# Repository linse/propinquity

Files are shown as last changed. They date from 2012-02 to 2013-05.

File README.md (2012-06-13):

Propinquity
===========

Propinquity is a full-body game that is a hybrid between fighting and dancing games. Two players wear proximity sensors on different body parts and as they move to the music, different sensors patches on their bodies light up to indicate when they are active. The players attempt to get as close as possible to active patches on the other player’s body to score points. The longer s(he) can stay “in the sweet spot” (but without actually touching), the higher the resulting score.

[Propinquity on the TAG website](http://playpr.hexagram.ca/projects/?proj=2)

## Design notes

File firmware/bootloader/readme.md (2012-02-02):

Propinquity Arduino Bootloader
==============================

In order to flash the Arduino bootloader onto the propinquity patch, simply run "make". You must make sure the port/programmer in the makefile match the port and programmer you are using.

It is important to use this makefile and NOT the bootloader flashing available in the Arduino IDE. The flashing in the Arduino IDE has the wrong clock rate and it will brick your propinquity patch.

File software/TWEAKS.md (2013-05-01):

# Where To Tweak Things in Propinquity

* Enable the hardware simulation IMPORANT MUST BE SET TO FALSE TO PLAY WITH REAL PATCHES
	* Location src/Propinquity.java line 28
	* Name: useSimulator
	* Range: true/false
	* Set to true if you need to use the hardware simulator, set to false if you're using real patches
* Adjust the prox sensor ranges
	* Location: src/hardware/Patch.java line 14-5
	* Name: MIN_RANGE, MAX_RANGE
	* Range: 0-1024 (actual maximum is closer to 1000, depends on prox sensors)
	* Adjust the range of the prox sensor in which you can score. MIN_RANGE, MAX_RANGE sets the range in which normal scoring occurs. Outside this range no scoring occurs
* Player Colors
	* Location src/PlayerConstants.java line 22-27
	* Name: PLAYER_COLORS, NEUTRAL_COLOR
	* Range: see the src/Color.java file for more colors
	* This sets the colors everywhere for neutral and players.
hes/gloves
* ProxLevel (normal levels) length
	* Location: src/ProxLevel.java line 17
	* Name: TOTAL_LEN
	* Range: > 0 (number in milliseconds)
	* Sets the total length of a ProxLevel in millisecond. For example set 180000ms for 180sec/3min
* Background Color Saturation
	* Location: src/LevelConstants.java line 17
	* Name: BACKGROUND_SAT_CAP
	* Range: 0-1
	* This number limits the maximum color saturation of the background when one player is winning. 0 being no saturation and 1 being full saturation
* Blinking speeds and duty cycle
	* Location: src/hardware/HardwareConstants.java line 15-18
	* Name: SLOW_BLINK, FAST_BLINK
	* Range: > 0 (in milliseconds)
	* Name: DEFAULT_DUTY_CYCLE
	* Range: 0-255 (0 -> 0%, 127 -> 50%, 255 -> 100%)
	* Sets the fast and slow blink speeds for the patches/gloves. You can also set how much of each blink period is on/off by adjusting the DEFAULT_DUTY_CYCLE
* Particle Sizes
	* Location: src/Particle.java line 17-20
	* Name: SMALL_SIZE, LARGE_SIZE, METABALL_OVERSIZE_FACTOR
	* Range: > 0
	* Set the size of the small and large particles. The METABALL_OVERSIZE_FACTOR affects how aggressively the particles "melt" into each other
* Particle spawning rates
	* Location: src/Player.java line 13-16
	* Name: SPAWN_DELAY_SHORT
	* Name: SPAWN_DELAY_MED
	* Name: SPAWN_DELAY_LONG (Not used right now, only used with SweetSpot)
	* Name: SPAWN_DELAY_TAU
	* Range: > 0
	* Sets the spawning rate of particles according to an exponential curve. SPAWN_DELAY_MED is the initial rate of spawning (in milliseconds). SPAWN_DELAY_SHORT is the final rate of spawning (in milliseconds). SPAWN_DELAY_TAU adjust the time the exponential curve takes to go from slow to fast (in milliseconds). The equations are on line 275 and 278.
* Patch and glove XBee addresses
	* Location src/PlayerConstants.java line 12-20
	* Name: PATCH_ADDR, GLOVE_ADDR
	* Range: > 0
	* Gives the Xbees addresses for the patches and gloves

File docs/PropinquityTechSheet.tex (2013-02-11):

\documentclass{article}

\pagestyle{empty} %Clear header and footer

\usepackage{times} %Font
\usepackage{soul} %Spacing

\usepackage{graphicx} %Images
\usepackage{subfig} %Subfigures

\usepackage{hyperref} %Link everything

\usepackage{enumitem}

\usepackage[small,compact]{titlesec} %Save on space between titles/sections

\graphicspath{{./media/}} %image folder

\begin{document}

\title{Propinquity - Technical Sheet \\ \vspace{-2em}}
\date{\today}

\maketitle

% \clearpage

\section*{Patch and Glove Features}

Each patch/glove is completely independent and uniquely addressed. Sensor values and feedback can be configured on a per patch/glove basis.

\subsection*{Communication}

\begin{itemize}[noitemsep,nolistsep]
	\item Xbees: bi-directional serial communication with computer.
	\item Serial port: programing port (arduino compatible) and serial communication.
\end{itemize}

\subsection*{Sensors}

\begin{itemize}[noitemsep,nolistsep]
	\item Proximity Sensor -- Sharp GP2D120 sensor: \\ Senses proximity in a 4 to 30 cm ranges. The sensor is connected to the patch/glove by a cable and could be mounted away from the main patch/glove. \\ {\em Propinquity gloves currently do not include proximity sensors.}
	\item Accelerometer -- MMA8452Q 3-axis accelerometer. \\ In addition to 3-axis acceleration information, the sensor has a number of built in event detection mechanisms detailed below.
\end{itemize}

\subsection*{Feedback}

\begin{itemize}[noitemsep,nolistsep]
	\item RGB LEDs. \\ 4 high brightness RGB LEDs (controlled together) are located in the corners of the patch/glove.
	\item Vibe Motor. \\ The coin cell vibe motor is connected via a cable and mounted separately. \\ {\em Proinquity patches do not currently include vibe motors.}
\end{itemize}

\subsection*{Expansion Ports}

The propinquity patches/gloves include 4 expansion ports connected to ADC pins (can also be used as digital pins). These are equivalent to the arduino A0, A1, A2 and A3 pins.

\pagebreak

\section*{Accelerometer Details}

\subsection*{General Functionality}

\begin{itemize}[noitemsep,nolistsep]
	\item 3-axis accelerometer sensor
	\item Adjustable sensitivity range (+- 2/4/8 G)
\end{itemize}

\subsection*{Special Functionality}

The accelerometer has specical functionality built in to detect certain events. These functions provide very robust and easy detection method. Technical details are available in the data-sheet.

\begin{itemize}[noitemsep,nolistsep]
	\item {\bf Freefall Detection:} \\ Detect the acceleration magnitude falling below a threshold. Often used to detect if the accelerometer is dropped and falling freely. Additionally a minimum time before triggering can be set (debouncing), this forces the condition to occur continuously for a certain interval of time before the event is confirmed.
	\item {\bf Motion Detection:} \\ Detect when the acceleration magnitude rises above a set threshold. Often used to detect the device being in use. Additionally a minimum time before triggering can be set (debouncing), this forces the condition to occur continuously for a certain interval of time before the event is confirmed.
	\item {\bf Transient Detection:} \\ Similar to motion detection but optionally pre-filtered with a high pass filter. This will remove constant acceleration such as gravity.
	\item {\bf Pulse Detection:} \\ Allows detection of pulses or taps, single or double. \\ ``Embedded single/double and directional pulse detection. This function has various customizing timers for setting the pulse time width and the latency time between pulses. There are programmable thresholds for all three axes. The pulse detection can be configured to run through the high-pass filter and also through a low-pass filter, which provides more customizing and tunable pulse-detection schemes.''
	\item {\bf Orientation Detection:} \\ ``Orientation detection algorithm with the ability to detect all 6 orientations.''
\end{itemize}

\end{document}

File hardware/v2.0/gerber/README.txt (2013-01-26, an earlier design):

Contact
------------------
Designer:

Specifications
------------------
* Green solder mask
* White silkscreen (top layer only)
* 3mils tolerance on drills
* 7mils spacings everywhere (checked)

Files
------------------
*.drd : 	excellon drill data
*.cmp : 	copper layer (TOP)
*.sol : 	copper layer (BOTTOM)
*.stc : 	soldermask layer (TOP)
*.sts : 	soldermask layer (BOTTOM)
*.plc : 	silkscreen layer (TOP)
*.pls : 	silkscreen layer (BOTTOM)

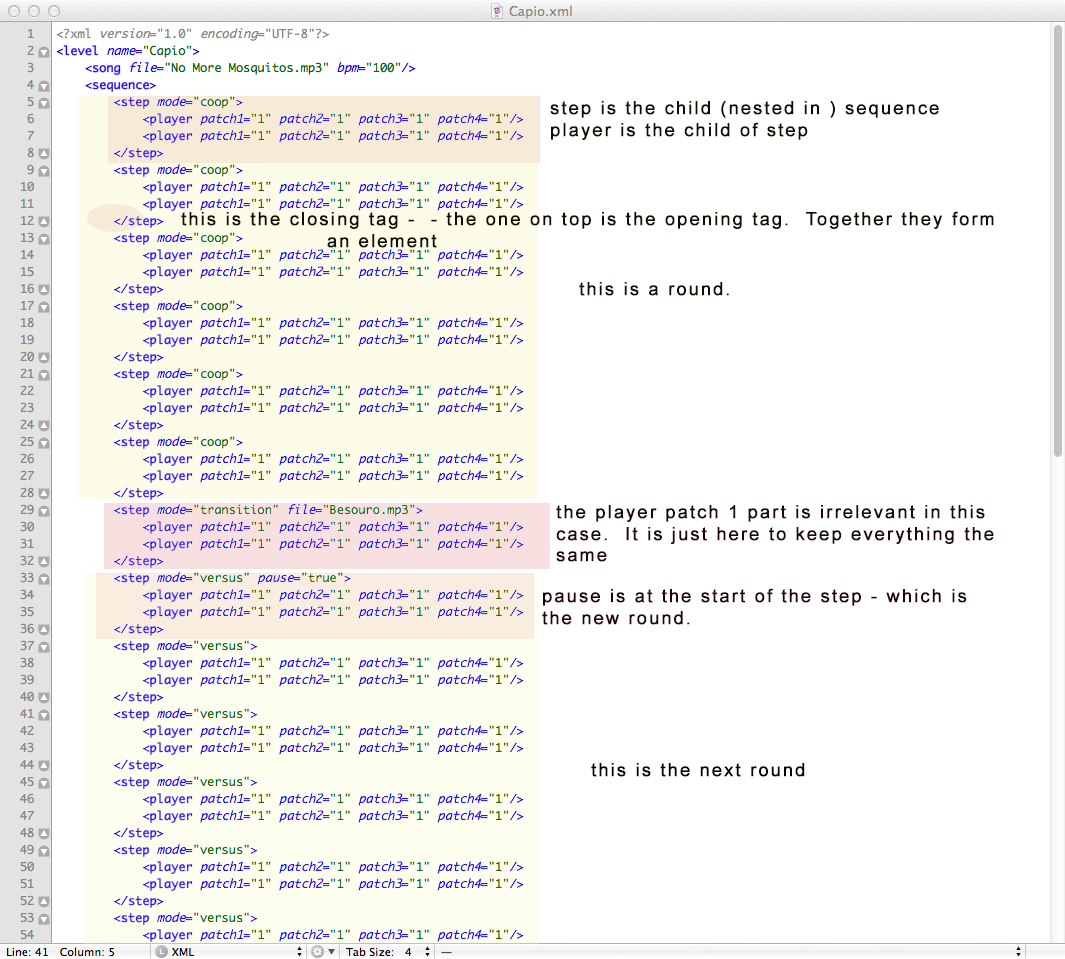
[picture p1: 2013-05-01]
docs/level.png

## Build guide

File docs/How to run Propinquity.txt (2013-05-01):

https://github.com/linse/propinquity

click on zip Ð and this is the latest.

Unzip

Open terminal

CD (change directory) command to go into the directory

CD Òname of directoryÓ  (or I can grab the folder I just unzipped and drag it next to CD space Ðpropinquity>software)
For example:
Janes-Mac-Pro:~ janetingley$ cd /Users/janetingley/Desktop/propinquity/Source\ Code/propinquity-May1/software

(I can also write ls (list) if I want to see what is in the directory.)

then type Ð ant

should run Ð if not Ð check the error message.  (if not Ð perhaps missing sound files?)

There is a launcher Ð Propinquity> software > launchers    may or may not work

Vocab

Level is comprised of 4 rounds

Details

Space bar Ð to move through the program when it is running.
Delete Ð backwards
Esc Ð quit
E Ð end Ð jumps to end
s- skip current level and goes to next transition
a Ð adjust the visuals (circle) and arrow keys Ð x and y axis.

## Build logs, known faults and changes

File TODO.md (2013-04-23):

# Propinquity TODOs

## Documentation
* High level documentation
	* OO diagram
	* Protocol specifications

## XBees
* XBee configuration should be saved and added to the git repo
* A new correct record of the XBee addresses should be added to the repo
* We need two full radio address spaces and a mechanism to switch between them.

## Work Schedule

My high level plan for the first block of time (24h) looks like this.

 * Review the new hardware. (8-12h)
 	* Make any improvements I can to the current boards (such as changing regulator etc).
 * Review software from the hackathon (4-8h)
 	* Read new code (particularly from marius)
 	* Organize and document a bit so it's a least somewhat maintainable
 * Examine and address what bugs I can such as those in my notes and from Marius' notes (8h+)
 * If time remains start think about the accelerometers

The other block of time (20h) was mainly for working with the accel. I'm thinking something like this.

 * Provide some examples of advanced accelerometer use for future reference
 * Consider some amendments to the Xbee protocol to work better with accel
 * Prototype the often discussed speed limited version of the basic propinquity game
 * Play test this prototype in the TAG lab

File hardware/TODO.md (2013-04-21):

# Hardware TODOs

## V2.0 Hardware

### Known Issues

* Regulator footprint accepts active low EN 3.3V regulators. This seems to be less common than active high especially with for LDOs with >100mA or more of current. This is a problem since is seems that we require at least that much current.
* No pins available for connecting a switch
* Topology of the circuit is not good for charging since everything is connected and running when you try and charge. This means the charger can't tell what's going on
* FTDI +5V connects directly to the +3v3 net, probably not nice for the +3v3 chips (e.g. accel and prox)
* Transistor is uncommon footprint (EBC?)
* The setup is unnecessarily connected to +3v3. It would draw less current and be more power efficient in general to run it off V+

### Current Status and Workarounds

* For regulator Some 100mA regulators are available with the current pinout, but current drive is marginal
* Alternatively use any pin with active high EN, bend up the pin and use a small wire to connect EN to closest V+
* Switches have been added by bending up the V+ pin on the battery Molex connector and putting a switch between the +ve leg of the molex connector and the V+ pad.
* Charging doesn't seem like it's consistently working. Probably have to disconnect batteries for the moment
* Ignoring FTDI issue for now. Pin could be removed from the header if it's an issue
* More common BCE or equivalent MOSFET can be installed upside down easily

## V2.1 Hardware

### Fixes

* Regulator footprint has active high EN polarity. Can accept bigger +3.3V regulators
* Added header for a switch that leave only the charger plugged in when it's in the off position. This should allow on/off and good charging
* +5V from the FTDI connector now connects to V+ via a jumper. This is optional for dev. In general it's probably not good to have the +5V attached to V+ since you risk damaging the battery.
* Flipped transistor footprint
* Step up runs directly off V+
* New routing of the PCB is 10mil tolerant where possible

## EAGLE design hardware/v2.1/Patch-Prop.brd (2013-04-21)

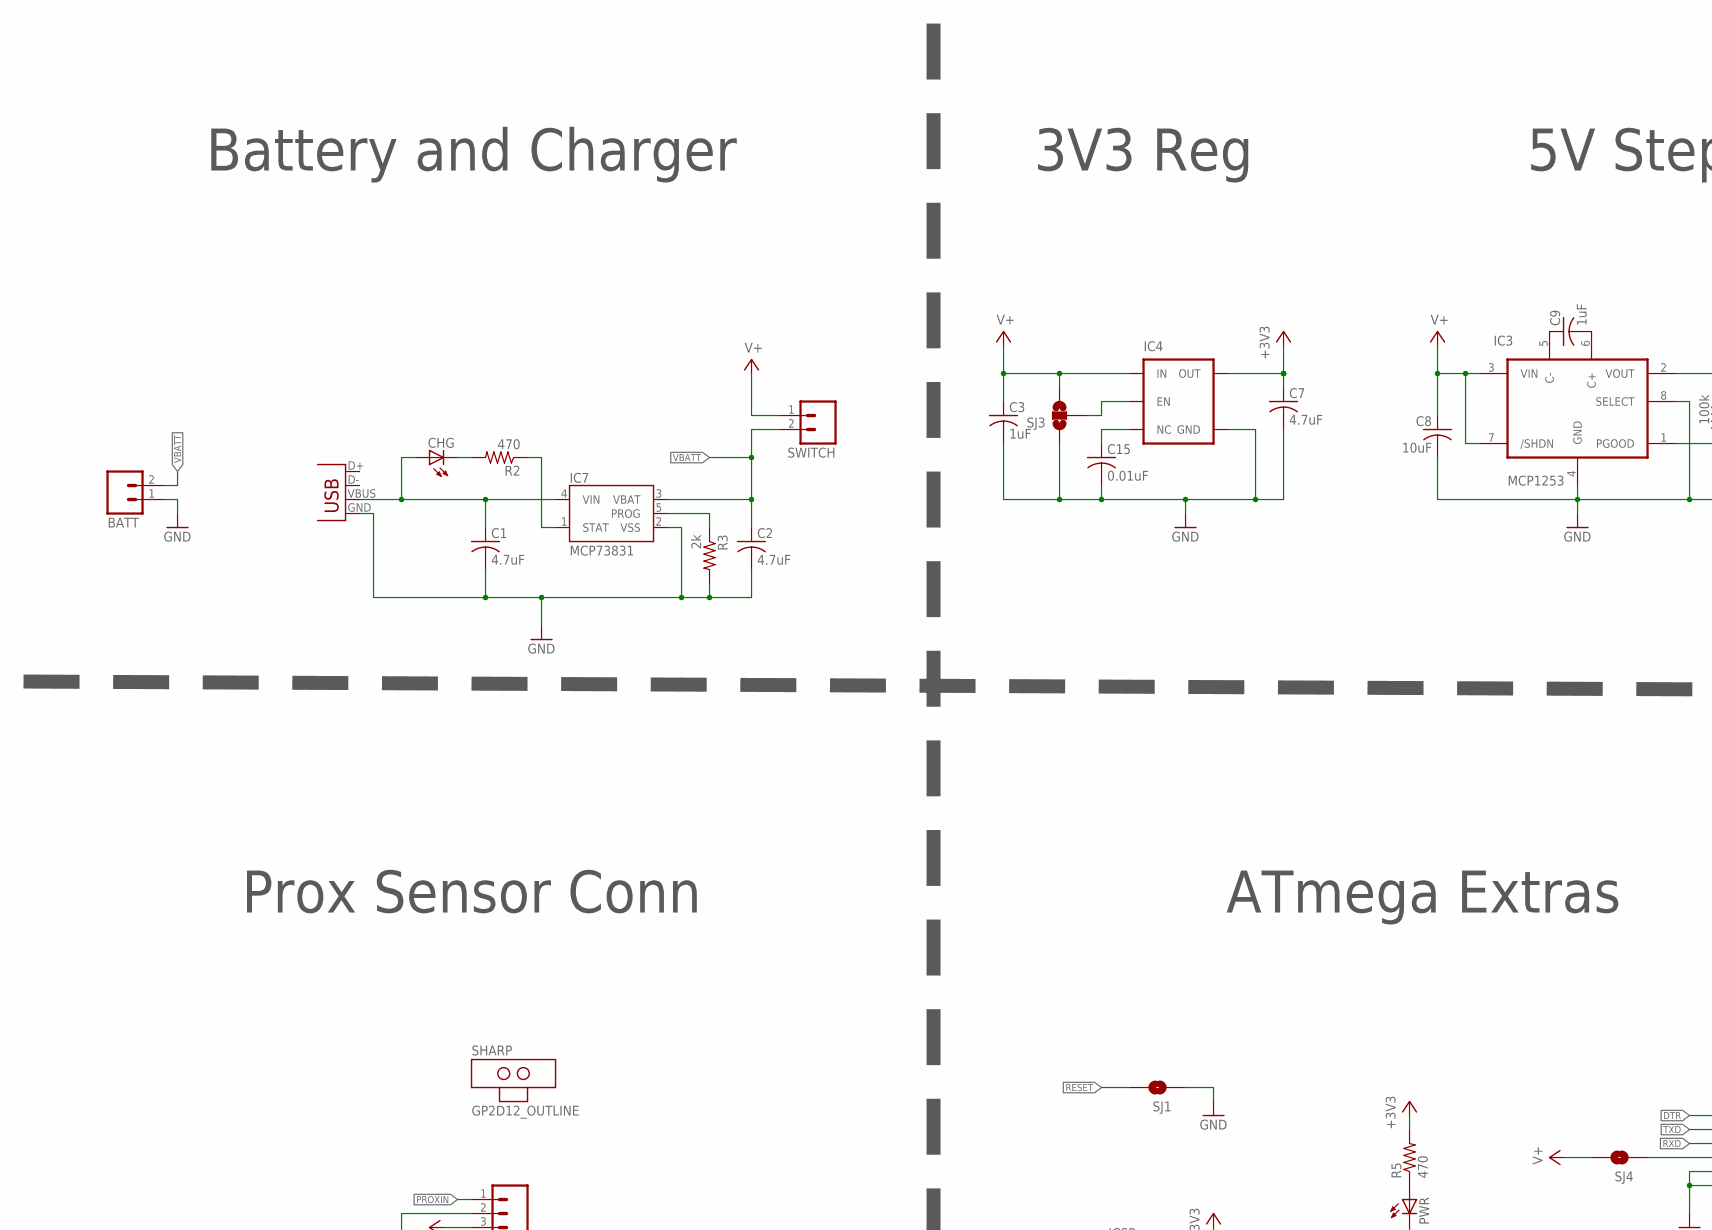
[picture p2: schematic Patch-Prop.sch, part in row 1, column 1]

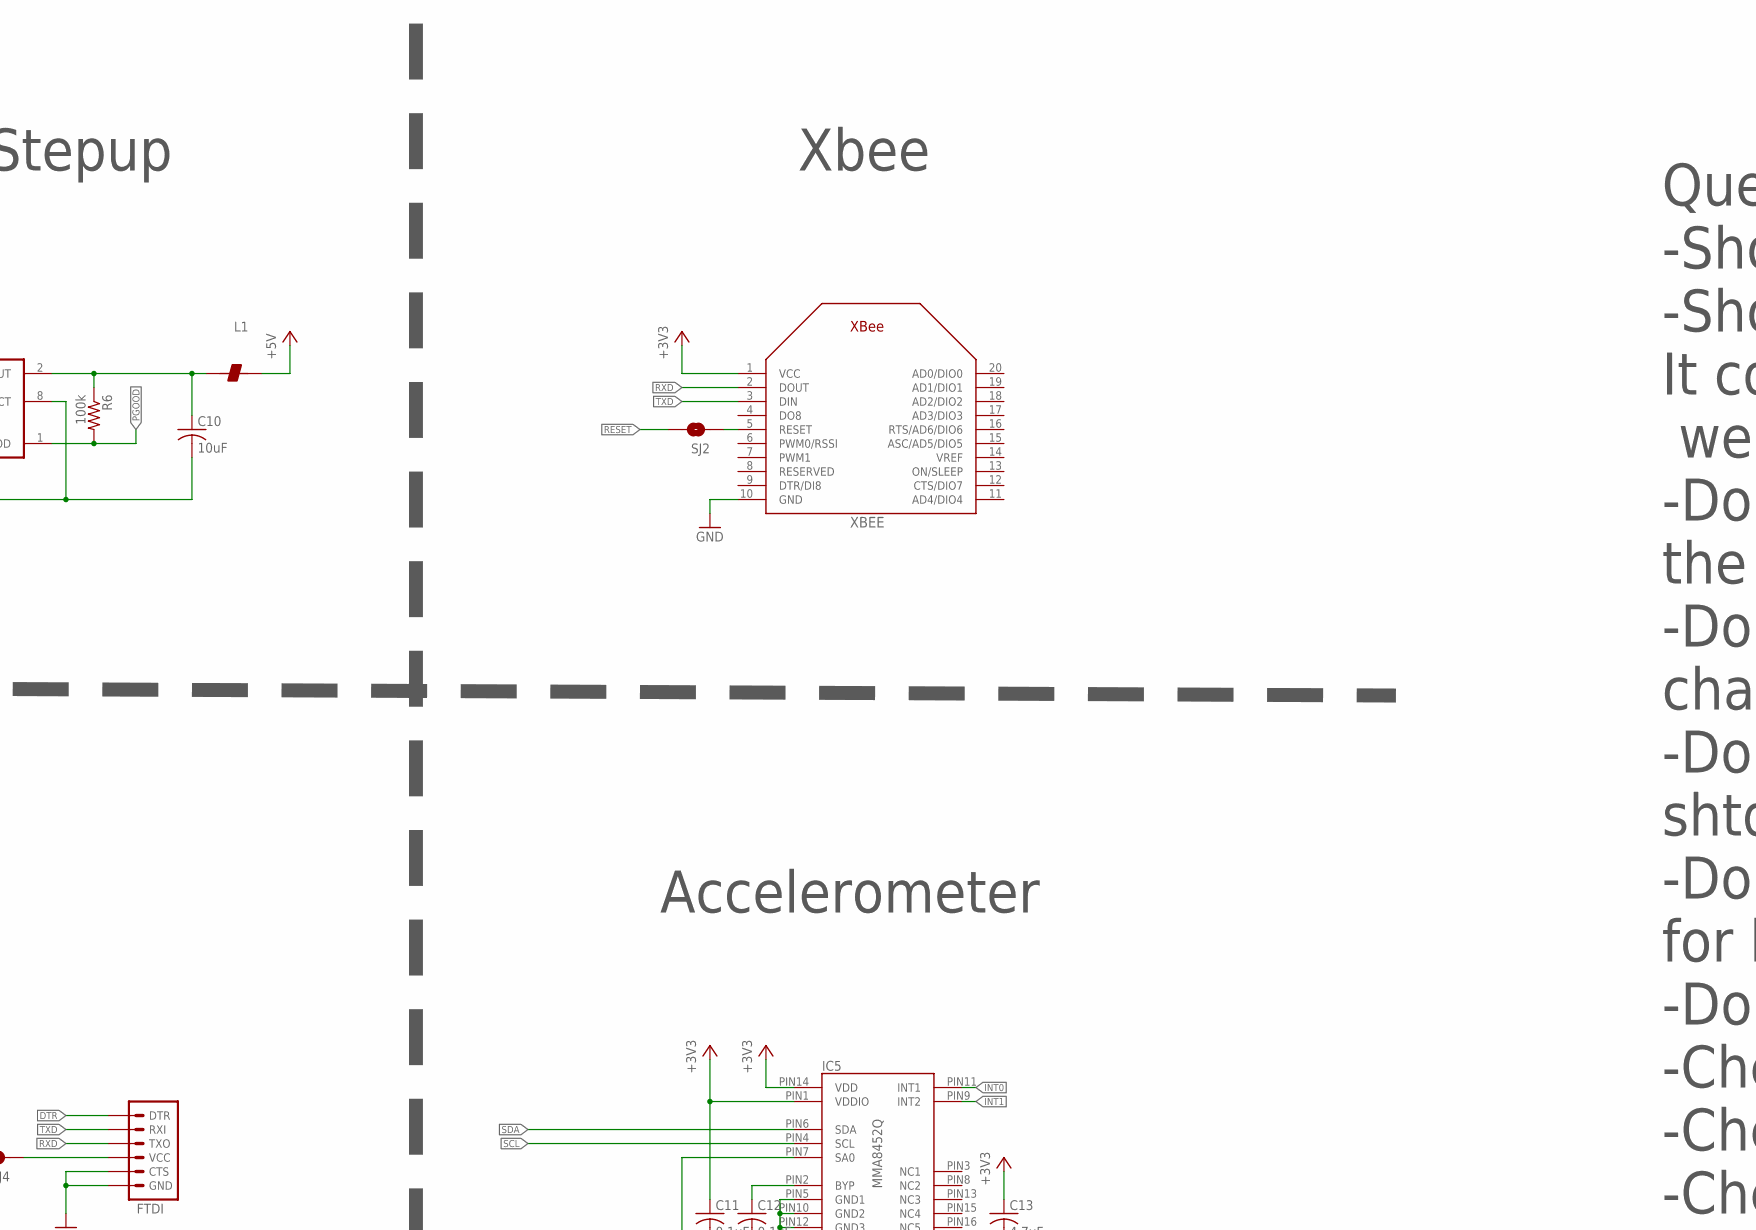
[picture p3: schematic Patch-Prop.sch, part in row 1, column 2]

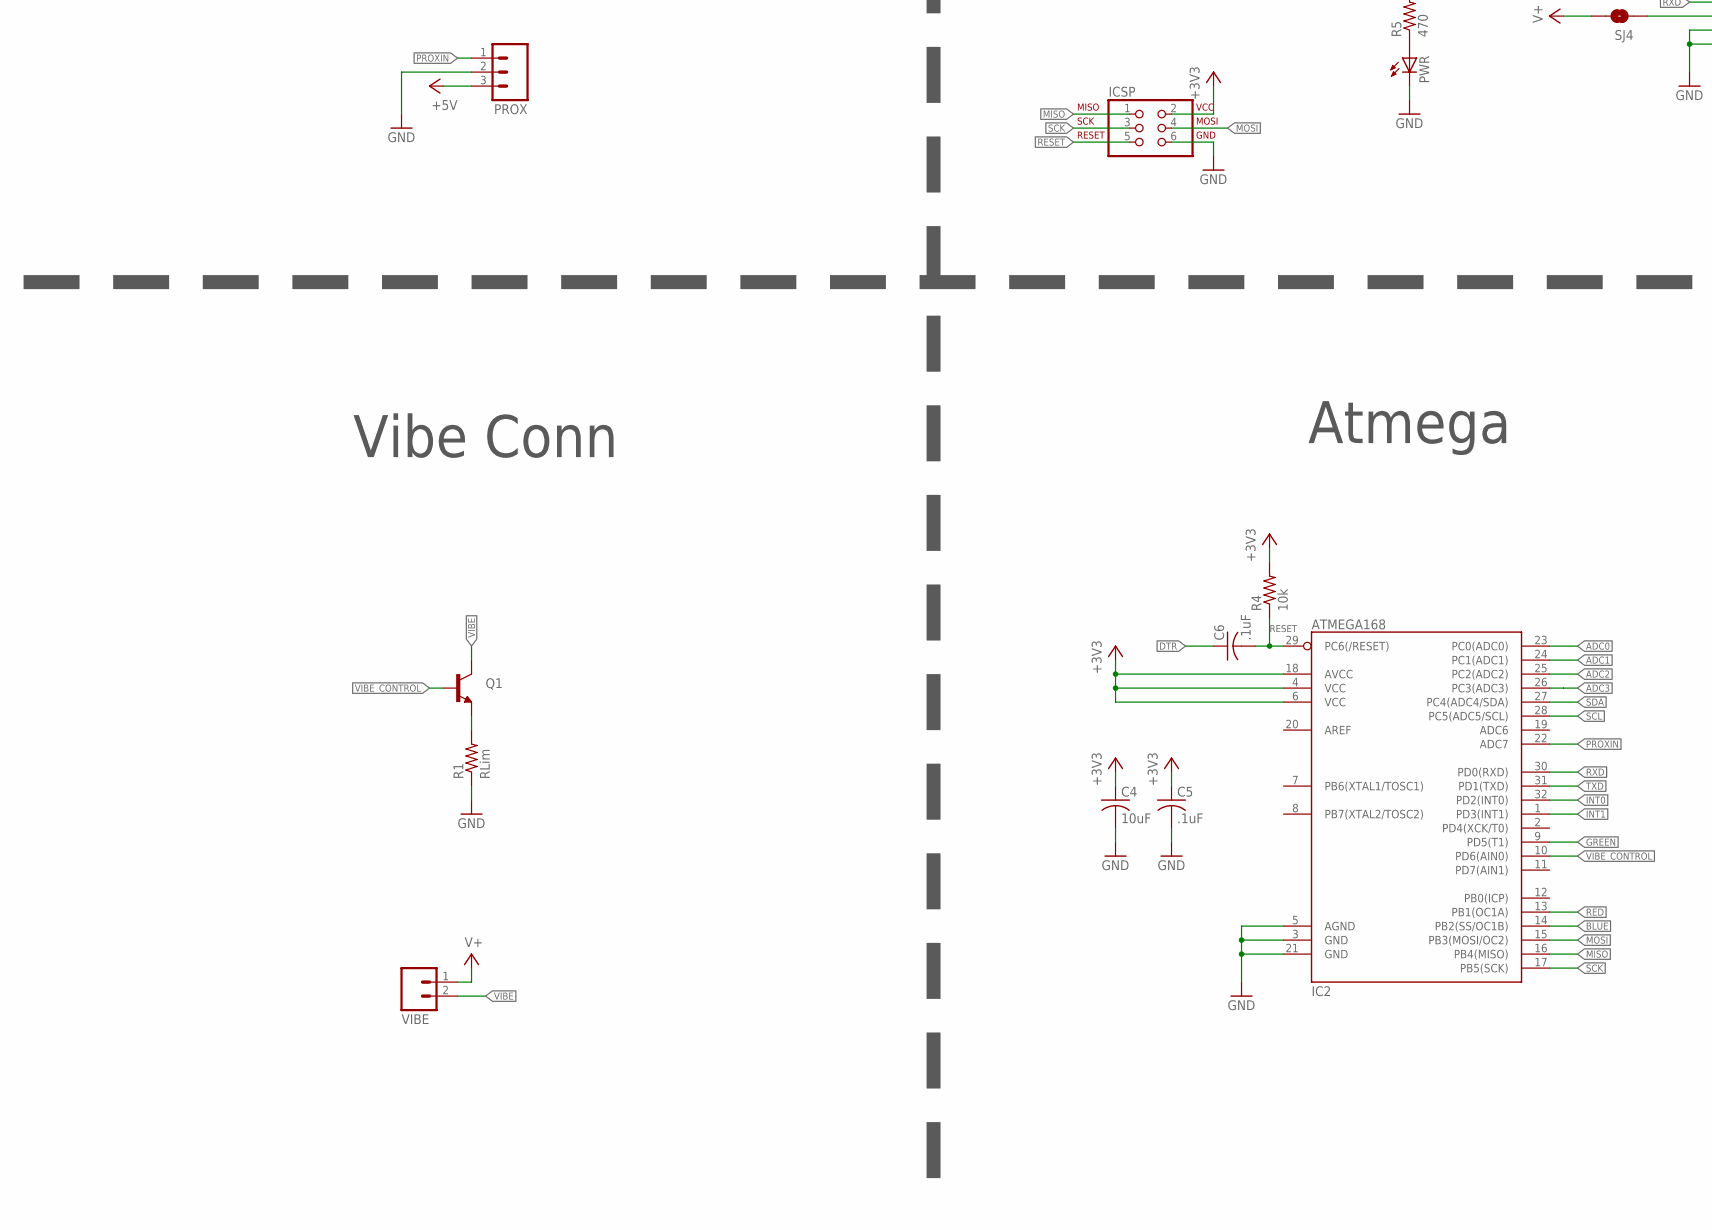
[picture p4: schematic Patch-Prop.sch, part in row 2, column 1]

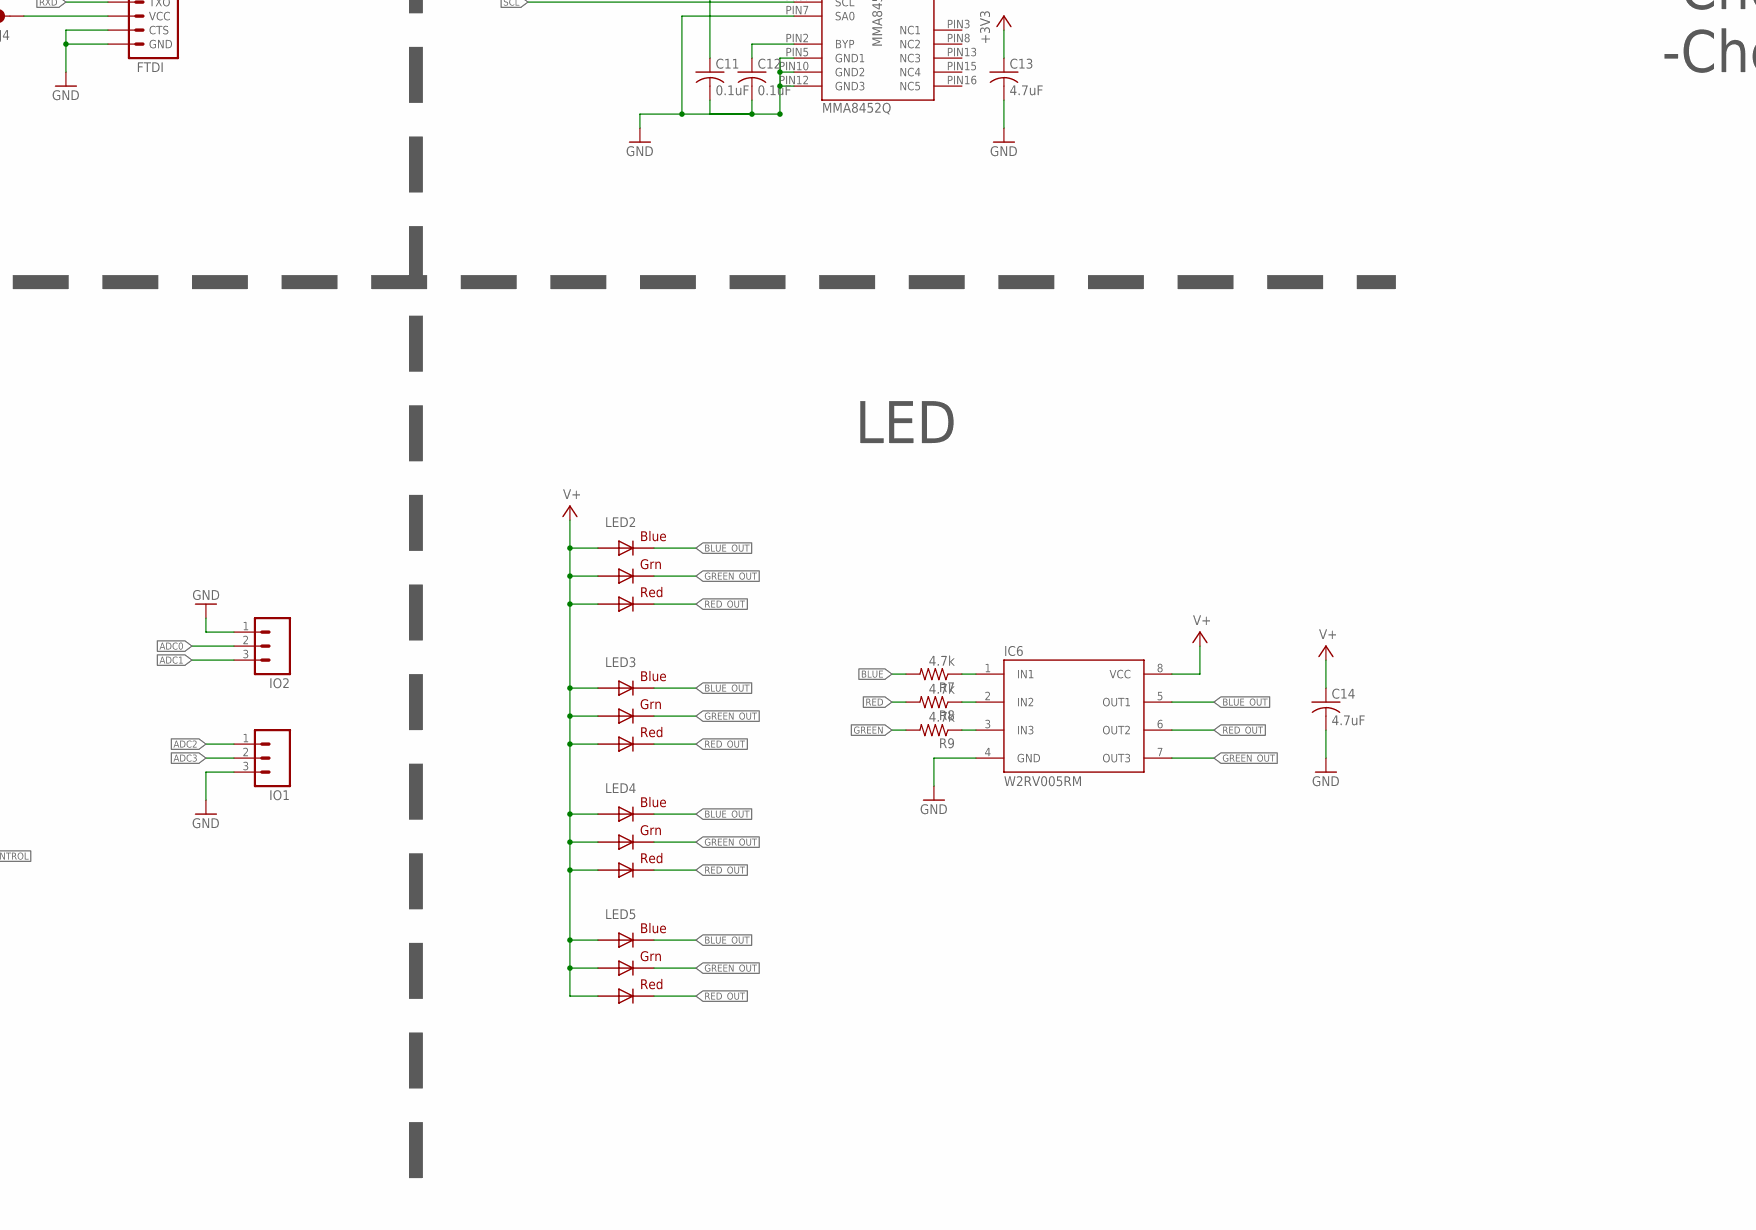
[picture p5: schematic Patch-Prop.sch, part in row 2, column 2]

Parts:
BATT: M02-JST-2MM-SMT; JST-2-SMD
C1, C2, C7, C13, C14: 4.7uF; C0603
C3, C9: 1uF; C0603
C4, C8, C10: 10uF; C0603
C5, C6: .1uF; C0603
C11, C12: 0.1uF; C0603
C15: 0.01uF; C0603
CHG: LEDCHIPLED_0805; CHIPLED_0805
FTDI: ARDUINO_SERIAL_PROGRAMPTH; 1X06
IC2: ATMEGA168; TQFP32-08
IC3: MCP1253; MSOP8
IC4: V_REG_TPS76433SOT23-5; SOT23-5
IC5: MMA8452Q; QFN-16
IC6: W2RV005RM; MSOP8
IC7: MCP73831; SOT23-5
ICSP: ISP-AVR910SMD; 2X03_BORDER
IO1, IO2: M03PTH; 1X03
L1: BEAD-0805; 0805
LED2, LED3, LED4, LED5: RGBLED5050
PROX: M03PTH; 1X03
PWR: LEDCHIPLED_0805; CHIPLED_0805
Q1: TRANSISTOR_NPNSOT23; SOT23
R1: RLim; R0603
R2, R5: 470; R0603
R3: 2k; R0603
R4: 10k; R0603
R6: 100k; R0603
R7, R8, R9: 4.7k; R0603
SHARP: GP2D12_OUTLINE
SJ1, SJ2, SJ4: SOLDERJUMPERNO; SJ_2S-NO
SJ3: SOLDERJUMPER_2WAYS; SJ_3
SWITCH: M02PTH; 1X02
USB: USBSMD; USB-MINIB
VIBE: M02PTH; 1X02
XBEE: XBEE

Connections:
+3V3: C4.1, C5.1, C7.1, C11.1, C13.1, IC2.4 (VCC), IC2.6 (VCC), IC2.18 (AVCC), IC4.5 (OUT), IC5.PIN1 (VDDIO), IC5.PIN14 (VDD), ICSP.2, R4.2, R5.2, XBEE.1 (VCC)
+5V: L1.2, PROX.3
ADC0: IC2.23 (PC0(ADC0)), IO2.2
ADC1: IC2.24 (PC1(ADC1)), IO2.3
ADC2: IC2.25 (PC2(ADC2)), IO1.1
ADC3: IC2.26 (PC3(ADC3)), IO1.2
BLUE: IC2.14 (PB2(SS/OC1B)), R7.2
BLUE_OUT: IC6.5 (OUT1), LED2.4 (BLUE_C), LED3.4 (BLUE_C), LED4.4 (BLUE_C), LED5.4 (BLUE_C)
DTR: C6.1, FTDI.1 (DTR)
GND: BATT.1 (2), C1.2, C2.2, C3.2, C4.2, C5.2, C7.2, C8.2, C10.2, C11.2, C12.2, C13.2, C14.2, C15.2, FTDI.5 (CTS), FTDI.6 (GND), IC2.3 (GND), IC2.5 (AGND), IC2.21 (GND), IC3.4 (GND), IC3.8 (SELECT), IC4.2 (GND), IC5.PIN5 (GND1), IC5.PIN7 (SA0), IC5.PIN10 (GND2), IC5.PIN12 (GND3), IC6.4 (GND), IC7.2 (VSS), ICSP.6, IO1.3, IO2.1, PROX.2, PWR.C, R1.1, R3.2, SJ1.1, SJ3.1, USB.GND, XBEE.10 (GND)
GREEN: IC2.9 (PD5(T1)), R9.2
GREEN_OUT: IC6.7 (OUT3), LED2.6 (GREEN_C), LED3.6 (GREEN_C), LED4.6 (GREEN_C), LED5.6 (GREEN_C)
INT0: IC2.32 (PD2(INT0)), IC5.PIN11 (INT1)
INT1: IC2.1 (PD3(INT1)), IC5.PIN9 (INT2)
MISO: IC2.16 (PB4(MISO)), ICSP.1
MOSI: IC2.15 (PB3(MOSI/OC2)), ICSP.4
unnamed: C15.1, IC4.4 (NC)
unnamed: IC4.3 (EN), SJ3.2
unnamed: C9.1, IC3.5 (C-)
unnamed: Q1.2 (E), R1.2
unnamed: PWR.A, R5.1
unnamed: C9.2, IC3.6 (C+)
unnamed: IC6.1 (IN1), R7.1
unnamed: CHG.C, R2.2
unnamed: IC6.2 (IN2), R8.1
unnamed: C10.1, IC3.2 (VOUT), L1.1, R6.1
unnamed: IC7.5 (PROG), R3.1
unnamed: IC6.3 (IN3), R9.1
unnamed: FTDI.4 (VCC), SJ4.1
unnamed: IC7.1 (STAT), R2.1
unnamed: C12.1, IC5.PIN2 (BYP)
unnamed: SJ2.1, XBEE.5 (RESET)
PGOOD: IC3.1 (PGOOD), R6.2
PROXIN: IC2.22 (ADC7), PROX.1
RED: IC2.13 (PB1(OC1A)), R8.2
RED_OUT: IC6.6 (OUT2), LED2.5 (RED_C), LED3.5 (RED_C), LED4.5 (RED_C), LED5.5 (RED_C)
RESET: C6.2, IC2.29 (PC6(/RESET)), ICSP.5, R4.1, SJ1.2, SJ2.2
RXD: FTDI.3 (TXO), IC2.30 (PD0(RXD)), XBEE.2 (DOUT)
SCK: IC2.17 (PB5(SCK)), ICSP.3
SCL: IC2.28 (PC5(ADC5/SCL)), IC5.PIN4 (SCL)
SDA: IC2.27 (PC4(ADC4/SDA)), IC5.PIN6 (SDA)
TXD: FTDI.2 (RXI), IC2.31 (PD1(TXD)), XBEE.3 (DIN)
USB_VIN: C1.1, CHG.A, IC7.4 (VIN), USB.VBUS
V+: C3.1, C8.1, C14.1, IC3.3 (VIN), IC3.7 (/SHDN), IC4.1 (IN), IC6.8 (VCC), LED2.1 (GREEN_A), LED2.2 (RED_A), LED2.3 (BLUE_A), LED3.1 (GREEN_A), LED3.2 (RED_A), LED3.3 (BLUE_A), LED4.1 (GREEN_A), LED4.2 (RED_A), LED4.3 (BLUE_A), LED5.1 (GREEN_A), LED5.2 (RED_A), LED5.3 (BLUE_A), SJ3.3, SJ4.2, SWITCH.1, VIBE.1
VBATT: BATT.2 (1), C2.1, IC7.3 (VBAT), SWITCH.2
VIBE: Q1.3 (C), VIBE.2
VIBE_CONTROL: IC2.10 (PD6(AIN0)), Q1.1 (B)

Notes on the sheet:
Battery and Charger
3V3 Reg
5V Stepup
Xbee
Accelerometer
ATmega Extras
Prox Sensor Conn
Vibe Conn
Atmega
LED
Questions: -Should the vibe have a connector? -Should the prox have a connector? It could just have header holes and we solder a cable with a connector -Do we want to use the shtdwn for the stepup or power good -Double check we are on PWM channels -Double check stepup select and shtdwn -Double chec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

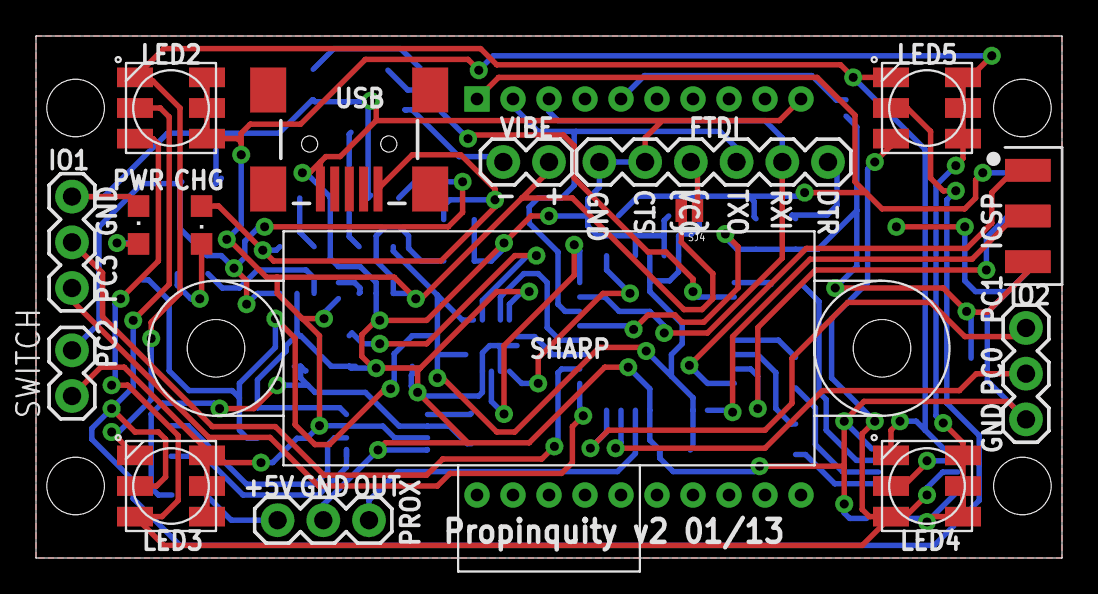
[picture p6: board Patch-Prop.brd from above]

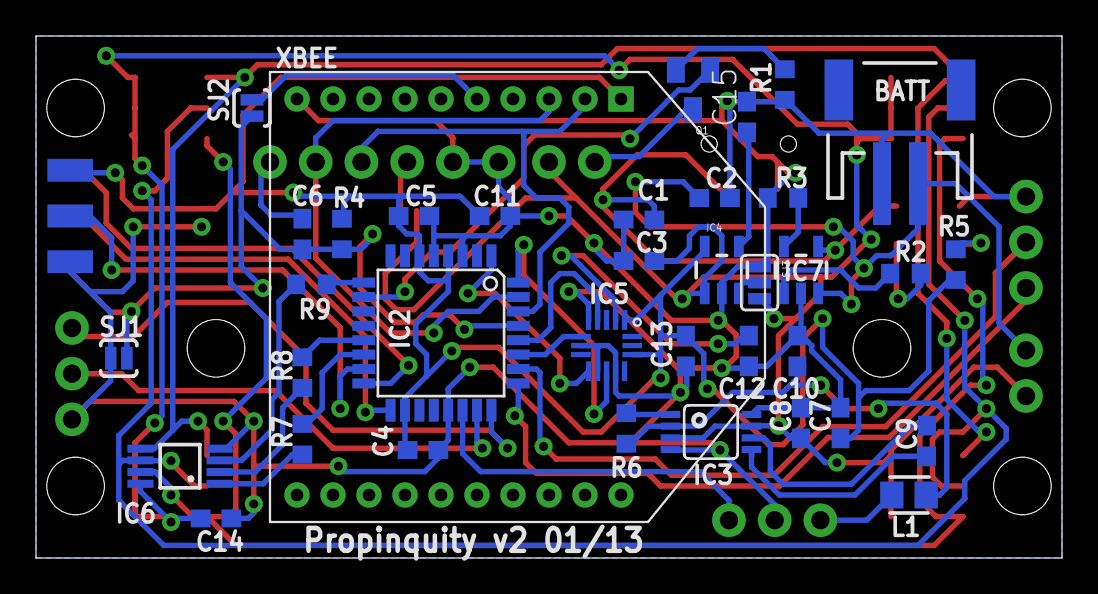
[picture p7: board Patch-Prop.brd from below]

Board: 2 copper layers, 57.0 x 29.0 mm, 53 parts (37 on the bottom side), 47 nets.

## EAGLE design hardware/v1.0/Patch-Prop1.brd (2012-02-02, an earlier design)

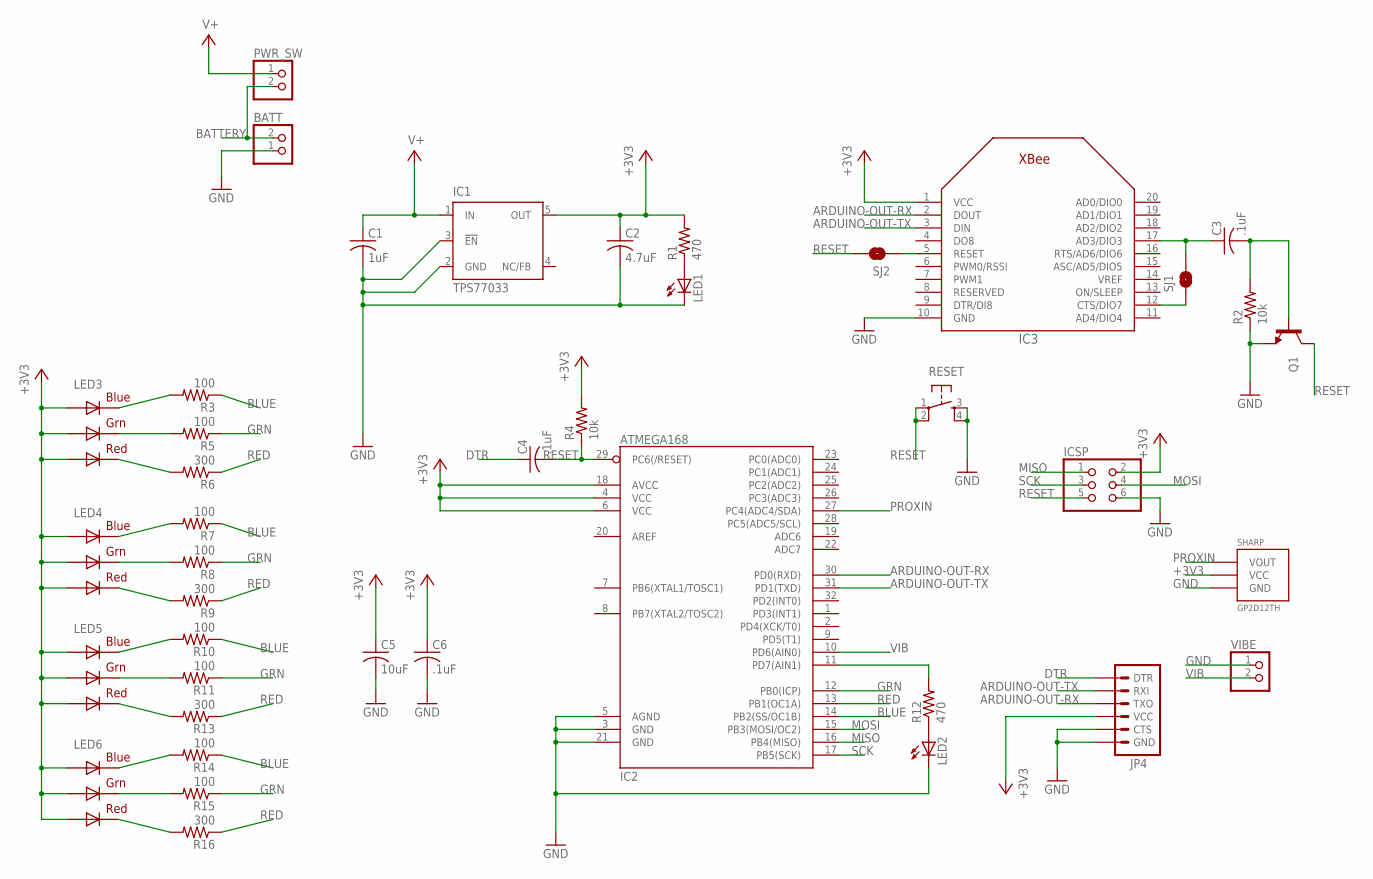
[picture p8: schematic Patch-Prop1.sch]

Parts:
BATT: JST_2PIN-SMT-RA; JST-PH-2-SMT-RA
C1: 1uF; C0603
C2: 4.7uF; C0603
C3, C4, C6: .1uF; C0603
C5: 10uF; C0603
IC1: TPS77033; SOT23-DBV
IC2: ATMEGA168; TQFP32-08
IC3: XBEE
ICSP: PINHD-2X3; 2X03
JP4: ARDUINO_SERIAL_PROGRAMSMD; 1X06-SMD
LED1, LED2: LEDCHIPLED_0805; CHIPLED_0805
LED3, LED4, LED5, LED6: RGBLED5050
PWR_SW: PINHD-1X2; 1X02
Q1: TRANSISTOR_NPNSOT89; SOT89
R1, R12: 470; R0603
R2, R4: 10k; R0603
R3, R5, R7, R8, R10, R11, R14, R15: 100; R0603
R6, R9, R13, R16: 300; R0603
RESET: TAC_SWITCHPTH; TACTILE-PTH
SHARP: GP2D12TH; GP2D12
SJ1, SJ2: SOLDERJUMPERNO; SJ_2S-NO
VIBE: PINHD-1X2; 1X02

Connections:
+3V3: C2.1, C5.1, C6.1, IC1.5 (OUT), IC2.4 (VCC), IC2.6 (VCC), IC2.18 (AVCC), IC3.1 (VCC), ICSP.2, JP4.4 (VCC), LED3.1 (GREEN_A), LED3.2 (RED_A), LED3.3 (BLUE_A), LED4.1 (GREEN_A), LED4.2 (RED_A), LED4.3 (BLUE_A), LED5.1 (GREEN_A), LED5.2 (RED_A), LED5.3 (BLUE_A), LED6.1 (GREEN_A), LED6.2 (RED_A), LED6.3 (BLUE_A), R1.2, R4.2, SHARP.VCC
ARDUINO-OUT-RX: IC2.30 (PD0(RXD)), IC3.2 (DOUT), JP4.3 (TXO)
ARDUINO-OUT-TX: IC2.31 (PD1(TXD)), IC3.3 (DIN), JP4.2 (RXI)
BATTERY: BATT.2 (1), PWR_SW.2
BLUE: IC2.14 (PB2(SS/OC1B)), R3.1, R7.1, R10.1, R14.1
DTR: C4.1, JP4.1 (DTR)
GND: BATT.1 (2), C1.2, C2.2, C5.2, C6.2, IC1.2 (GND), IC1.3 (!EN), IC2.3 (GND), IC2.5 (AGND), IC2.21 (GND), IC3.10 (GND), ICSP.6, JP4.5 (CTS), JP4.6 (GND), LED1.C, LED2.C, Q1.3 (E), R2.1, RESET.3, RESET.4, SHARP.GND, VIBE.1
GRN: IC2.12 (PB0(ICP)), R5.1, R8.1, R11.1, R15.1
MISO: IC2.16 (PB4(MISO)), ICSP.1
MOSI: IC2.15 (PB3(MOSI/OC2)), ICSP.4
unnamed: C3.1, IC3.17 (AD3/DIO3), SJ1.2
unnamed: C3.2, Q1.1 (B), R2.2
unnamed: LED1.A, R1.1
unnamed: LED2.A, R12.1
unnamed: IC2.11 (PD7(AIN1)), R12.2
unnamed: LED4.4 (BLUE_C), R7.2
unnamed: LED3.5 (RED_C), R6.2
unnamed: LED3.4 (BLUE_C), R3.2
unnamed: LED3.6 (GREEN_C), R5.2
unnamed: LED4.6 (GREEN_C), R8.2
unnamed: LED5.4 (BLUE_C), R10.2
unnamed: LED4.5 (RED_C), R9.2
unnamed: LED5.5 (RED_C), R13.2
unnamed: LED5.6 (GREEN_C), R11.2
unnamed: LED6.4 (BLUE_C), R14.2
unnamed: LED6.6 (GREEN_C), R15.2
unnamed: LED6.5 (RED_C), R16.2
unnamed: IC3.12 (CTS/DIO7), SJ1.1
unnamed: IC3.5 (RESET), SJ2.1
PROXIN: IC2.27 (PC4(ADC4/SDA)), SHARP.VOUT
RED: IC2.13 (PB1(OC1A)), R6.1, R9.1, R13.1, R16.1
RESET: C4.2, IC2.29 (PC6(/RESET)), ICSP.5, Q1.2 (C), R4.1, RESET.1, RESET.2, SJ2.2
SCK: IC2.17 (PB5(SCK)), ICSP.3
V+: C1.1, IC1.1 (IN), PWR_SW.1
VIB: IC2.10 (PD6(AIN0)), VIBE.2

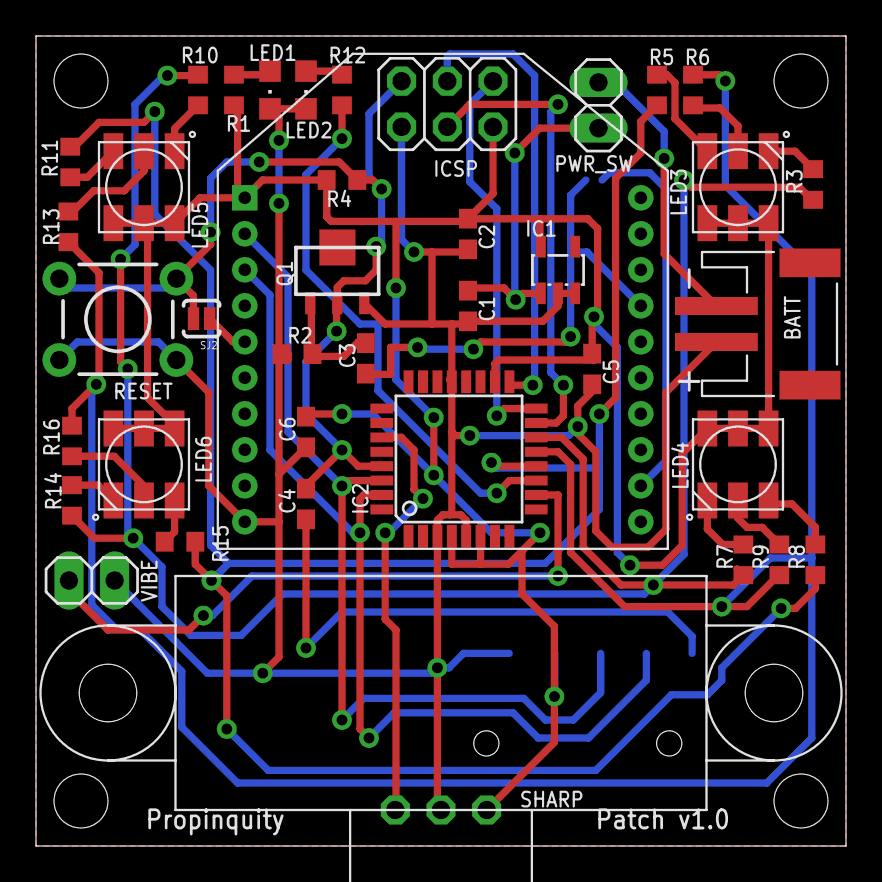
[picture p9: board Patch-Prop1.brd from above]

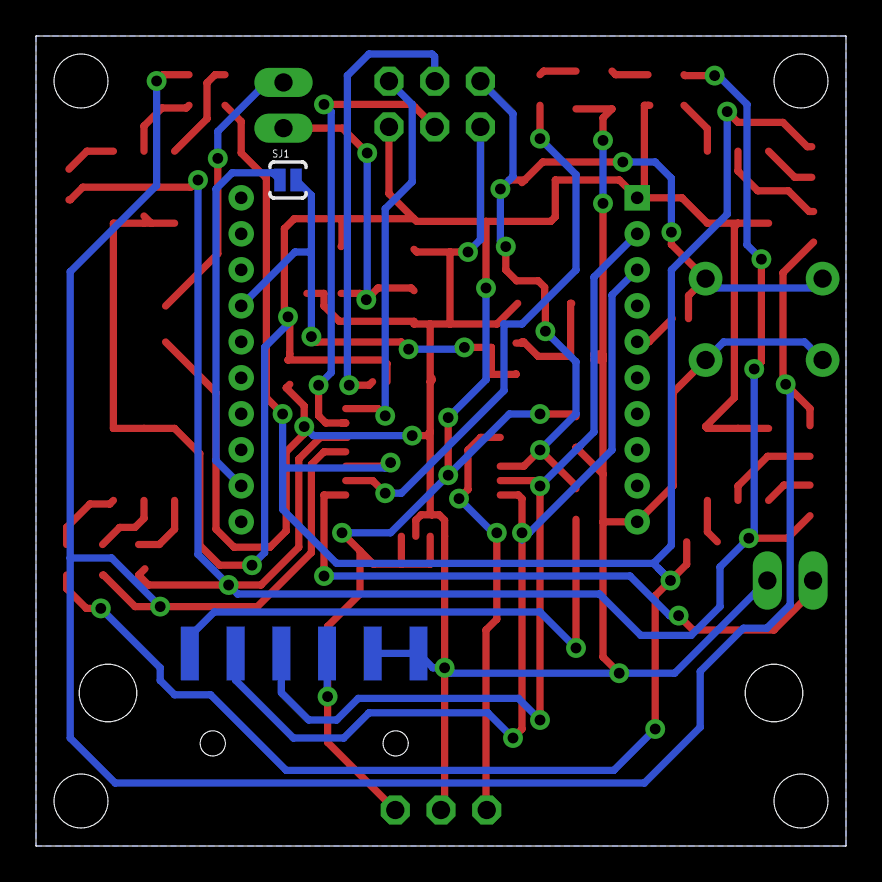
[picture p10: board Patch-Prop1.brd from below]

Board: 2 copper layers, 45.0 x 45.0 mm, 41 parts (2 on the bottom side), 35 nets.

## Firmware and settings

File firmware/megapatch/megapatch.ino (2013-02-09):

/**
 * Arduino Pro or Pro Mini (3.3V, 8 mHz) with Atmega 328
 *
 */

#include <Timer.h>
#include <Wire.h>
#include <XBee.h>
#include "MMA8452Q.h"
// #include <TimerOne.h>

// #define DEBUG

/* ---- Protocol ---- */

 enum PacketType {
 	MODE_PACKET          = 0,
 	CLEAR_PACKET         = 1,

	PROX_PACKET          = 2,

	ACCEL_XYZ_PACKET     = 3,
	ACCEL_INT0_PACKET    = 4,
	ACCEL_INT1_PACKET    = 5,

	ACCEL_CONF_PACKET    = 6,

	COLOR_PACKET         = 7,
	COLOR_DUTY_PACKET    = 8,
	COLOR_PERIOD_PACKET  = 9,
	COLOR_WAVEFORM_PACKET = 13,

	VIBE_PACKET          = 10,
	VIBE_DUTY_PACKET     = 11,
	VIBE_PERIOD_PACKET   = 12

 };

/* ---- Pin List ---- */

#define RED_LED_PIN    10
#define GREEN_LED_PIN  9
#define BLUE_LED_PIN   5

#define VIBE_PIN       6

#define PROX_PIN       A7 // Pin 21 Not available on normal arduino

/* ---- Accel ---- */

#define ADDR_DEVICE 0x1C

uint8_t accel_ok = 0;

uint8_t xyz[3];

uint8_t accel_flag = 0;
uint8_t accel_period = 10;

/* ---- Prox ----*/

#define PROX_AVG_LEN 8
#define PROX_AVG_SHIFT 3

uint8_t prox_val_pointer = 0;
uint16_t avg_prox_val = 0;
uint16_t prox_val[PROX_AVG_LEN];

uint8_t prox_flag = 0;
uint8_t prox_send_period = 10;
uint8_t prox_read_period = 1;

/* ---- Vibe/LEDs ----- */

uint8_t rgb[3] = {0, 0, 0};

uint8_t led_on = 1;
uint8_t led_duty = 0;
uint8_t led_period = 0;
uint8_t led_waveform = 0;

uint8_t vibe_level = 0;

uint8_t vibe_on = 1;
uint8_t vibe_duty = 0;
uint8_t vibe_period = 0;

/* ---- Global ---- */

#define ACTIVE_MODE 0
#define PROX_MODE 1
#define ACCEL_XYZ_MODE 2
#define ACCEL_INT0_MODE 3
#define ACCEL_INT1_MODE 4

uint8_t mode = 0;

/* ---- Timer ---- */

Timer t;
uint16_t time_counter = 0;

/* ---- XBee/Wireless ---- */

#define XBEE_BASE_ADDR 0

XBee xbee = XBee();
Tx16Request tx;
Rx16Response rx = Rx16Response();

void setup(void) {
	pinMode(RED_LED_PIN, OUTPUT);
	pinMode(BLUE_LED_PIN, OUTPUT);
	pinMode(GREEN_LED_PIN, OUTPUT);

	pinMode(VIBE_PIN, OUTPUT);

	pinMode(PROX_PIN, INPUT);
	pinMode(A0, INPUT);
	pinMode(A3, INPUT);

	pinMode(SDA, INPUT);
	pinMode(SCL, INPUT);	

	pinMode(2, INPUT);
	pinMode(3, INPUT);

	digitalWrite(2, HIGH);
	digitalWrite(3, HIGH);

	reset();

	#ifdef DEBUG
	Serial.begin(9600);
	Serial.println("Boot");
	setMode((1 << ACTIVE_MODE) | (1 << PROX_MODE));
	#endif

	Wire.begin(); // join i2c bus

	accel_reset();
	accel_config();

	// attachInterrupt(0, accel_int0, CHANGE);
	// attachInterrupt(1, accel_int1, CHANGE);

	t.every(10, timerCallback);

	// Timer1.initialize(10000); //1000 microseconds -> 10 milliseconds
	// Timer1.attachInterrupt(timerCallback); // attach the service routine here

	#ifndef DEBUG
	xbee.begin(38400);	
	#endif
}

void loop(void) {
	t.update();

	#ifndef DEBUG
	xbee.readPacket(); // Read packet, return after 500ms timeout

	XBeeResponse response = xbee.getResponse();
	if(response.isAvailable()) {
		if(response.getApiId() == RX_16_RESPONSE) {
			response.getRx16Response(rx); // Get RX response
			parse_data(rx.getData(), rx.getDataLength());
		}
	}
	#endif

	if(!(mode & (1 << ACTIVE_MODE))) {
		//Disabled, lights and vibe off
		vibe(0);
		color(0, 0, 0);
	} else {
		if((mode & (1 << PROX_MODE)) && prox_flag) {
			send_prox(avg_prox_val);
			prox_flag = 0;
		}

		if(accel_ok) {
			if((mode & (1 << ACCEL_XYZ_MODE)) && accel_flag) {
				accel_reg_multi_read(OUT_X_MSB, xyz, 3);				
				send_accel_XYZ(xyz[0], xyz[1], xyz[2]);

				accel_flag = 0;
			}

			if((mode & (1 << ACCEL_INT0_MODE))) {

			}

			if((mode & (1 << ACCEL_INT1_MODE))) {
				uint8_t tra_mt_src = accel_reg_read(TRANSIENT_SRC);
				if(tra_mt_src & (1 << T_EA)) {
					send_accel_int1(tra_mt_src);
				}
			}
		}

		updateVibe();
		updateLEDs();
	}
}

/**
 * Set the data out flag every ~10ms.
 */
void timerCallback(void) {
	if((time_counter % prox_read_period) == 0) {
		if(mode & (1 << PROX_MODE)) {
			//Prox enable
			uint16_t an[3];
			an[0] = analogRead(A0);
			an[1] = analogRead(A3);
			an[2] = analogRead(A7);

			uint16_t max_an = 0;
			for(uint16_t i = 0;i < 3;i++) {
				if(an[i] > max_an) max_an = an[i];
			}

			prox_val[prox_val_pointer] = max_an;
			prox_val_pointer = (prox_val_pointer+1)%PROX_AVG_LEN;

			avg_prox_val = 0;
			for(uint8_t i = 0;i < PROX_AVG_LEN;i++) {
				avg_prox_val += prox_val[i];
			}

			avg_prox_val = avg_prox_val >> PROX_AVG_SHIFT; //Divide by 8
		}
	}
	if((time_counter % prox_send_period) == 0) prox_flag = 1;
	if((time_counter % accel_period) == 0) accel_flag = 1;

	if(led_period == 0 || led_duty == 255) led_on = 1;
	else if((time_counter % led_period) < (uint8_t)(led_duty*led_period/255)) led_on = 1;
	else led_on = 0;

	if(vibe_period == 0 || vibe_duty == 255) vibe_on = 1;
	else if((time_counter % vibe_period) < (uint8_t)(vibe_duty*vibe_period/255)) vibe_on = 1;
	else vibe_on = 0;
	
	time_counter++;
}

/**
 * Reset patch
 */
void reset(void) {
	accel_flag = 0;
	prox_flag = 0;

	avg_prox_val = 0;
	for(uint8_t i = 0;i < PROX_AVG_LEN;i++) prox_val[i] = 0;

	vibe_level = 0;

	vibe_on = 0;
	vibe_duty = 0;
	vibe_period = 0;

	rgb[0] = rgb[1] = rgb[2] = 0;

	led_on = 0;
	led_duty = 0;
	led_period = 0;
	led_waveform = 0;

	color(0, 0, 0);
	vibe(0);

	setMode(0);
}

/* ---- Accel ---- */

void accel_reset(void) {
	#ifdef DEBUG
	Serial.println("Accel Reset Started");
	#endif

	accel_ok = 1;
	uint8_t tmp_accel_ok = 0;

	//Reset the accelerometer
	accel_reg_write(CTRL_REG2, (1 << RST));

	//Wait for reset to complete (blink yellow for wait state)
	int timer = 0;

	while(timer < 1000) { //Wait up to 1 second for reset
		if((accel_reg_read(CTRL_REG2) & (1 << RST)) == 0 && accel_reg_read(WHO_AM_I) == 0x2A) {
			tmp_accel_ok = 1;
			break;
		}

		if(timer % 200 < 100) color(20, 20, 0); //Blink yelow
		else color(0, 0, 0);

		timer++;
		delay(1);
	}

	accel_ok = tmp_accel_ok;

	if(accel_ok) {
		//Green for ok
		#ifdef DEBUG
		Serial.println("Reset Complete, WHO_AM_I Ok");
		#endif
		color(0, 40, 0);
		delay(500);
	} else {
		//Red for fail
		#ifdef DEBUG
		Serial.println("Reset Failed, Accel disabled");
		#endif
		color(40, 0, 0);
		delay(500);
	}
}

void accel_config(void) {	
	//IMPORTANT: all registers must be set with the accelerometer in STANDBY

	accel_enable(0);

	accel_reg_write(CTRL_REG1,  (1 << DR1) | (1 << DR0) | (1 << F_READ)); //Fast read 8 bit mode, 100Hz, Normal mode
	accel_reg_write(XYZ_DATA_CFG, (1 << HPF_OUT) | (0 << FS1) | (1 << FS0)); //Output high pass data, set range +-4g
	accel_reg_write(HP_FILTER_CUTOFF, (1 << SEL1)); //High pass second lowest setting
	
	// accel_reg_write(CTRL_REG3, (1 << IPOL) | (1 << PP_OD)); //Interrupts are active high, push-pull
	// accel_reg_write(CTRL_REG4, (1 << INT_EN_TRANS)); //Enable FF_MT to the interrupt controller
	// accel_reg_write(CTRL_REG5, (1 << INT_CFG_TRANS)); //Route to accel int1 -> arduino int0

	//Set up motion

	//Set the freefall/motin configuration registers to detect motion events on XYZA
	// accel_reg_write(FF_MT_CFG,
	// 	(1 << FF_MT_ELE) | //Event latching, clear on read
	// 	(1 << OAE) | //Use in motion detection mode
	// 	(1 << ZEFE) |
	// 	(1 << YEFE) |
	// 	(1 << XEFE) //Enable XYZ axis
	// );

	// uint8_t motion_threshold = 20; //15.87 -> 1G, value must be 7 bits, 0.063g/LSB
	// uint8_t motion_debounce = 1; //10ms per increment, value is 8 bits

	// accel_reg_write(FF_MT_THS, (uint8_t)(
	// 	(0 << DBCNTM) | //Clear debounce counter when motion falls below threshold
	// 	((motion_threshold & 0x7F) << THS) //Motion threshold (7 bits)
	// ));
	
	// accel_reg_write(FF_MT_COUNT, motion_debounce); //Debounce count

	// // Transient

	//Set the freefall/motin configuration registers to detect motion events on XYZA
	accel_reg_write(TRANSIENT_CFG,
		(1 << T_ELE) | //Event latching, clear on read
		(1 << ZTEFE) |
		(1 << YTEFE) |
		(1 << XTEFE) | //Enable XYZ axis
		(0 << HPF_BYP) //Keep the high pass
	);

	uint8_t transient_threshold = 20; //15.87 -> 1G, value must be 7 bits, 0.063g/LSB
	uint8_t transient_debounce = 1; //10ms per increment, value is 8 bits

	accel_reg_write(TRANSIENT_THS, (uint8_t)(
		(0 << DBCNTM) | //Decrement debounce counter when motion falls below threshold
		((transient_threshold & 0x7F) << THS) //Motion threshold (7 bits)
	));
	
	accel_reg_write(TRANSIENT_COUNT, transient_debounce); //Debounce count

	accel_enable(1);
}

void accel_enable(uint8_t enable) {
	uint8_t cur_val = accel_reg_read(CTRL_REG1); //TODO: Check that this actually "save" the previous value properly

	if(enable) {
		accel_reg_write(CTRL_REG1, cur_val | (1 << ACTIVE)); //Active mode
	} else {
		accel_reg_write(CTRL_REG1, cur_val & ~(0 << ACTIVE)); //Standby mode
	}
}

void accel_reg_write(uint8_t reg_addr, uint8_t data) {
	accel_reg_multi_write(reg_addr, &data, 1);
}

void accel_reg_multi_write(uint8_t reg_addr, uint8_t* data, int len) {
	if(!accel_ok) return;
	Wire.beginTransmission(ADDR_DEVICE);
	Wire.write(reg_addr);
	for(uint8_t i = 0;i < len;i++) {
		Wire.write(data[i]);
	}
	if(Wire.endTransmission() > 0) {
		accel_error();
	}
}

uint8_t accel_reg_read(uint8_t reg_addr) { 
	if(!accel_ok) return 0;
	uint8_t result = 0;
	accel_reg_multi_read(reg_addr, &result, 1);
	return result;
}

void accel_reg_multi_read(uint8_t reg_addr, uint8_t* data, int len) { 
	if(!accel_ok) return;
	Wire.beginTransmission(ADDR_DEVICE);
	Wire.write(reg_addr);
	if(Wire.endTransmission(false) > 0) { //Do not send stop condition, this will send a repeat start instead
		accel_error();
	}
	Wire.requestFrom(ADDR_DEVICE, len);
	//TODO: Implement OnReceive for less delay?
	for(uint8_t i = 0;i < len;i++) {
		if(Wire.available() > 0) {
			data[i] = Wire.read();
		} else {
			data[i] = 0;
			accel_error();
		}
	}
}

void accel_int0() {
	//Nothing yet handle interrupt 2
}

void accel_int1(void) {
	//Nothing yet handle interrupt 1
}

void accel_error() {
	//TODO: Some sort of error_count, try reseting device or eventually disabling it
}

/* ---- Xbee ---- */

void send_accel_int1(uint8_t tra_mt_src) {
	uint8_t outPacket[2];

	outPacket[0] = ACCEL_INT1_PACKET;
	outPacket[1] = tra_mt_src;

	#ifdef DEBUG
	Serial.print("int0 ");
	Serial.println(tra_mt_src);
	#else
	tx = Tx16Request(XBEE_BASE_ADDR, outPacket, 2);

	xbee.send(tx);
	#endif
}

void send_accel_XYZ(uint8_t x, uint8_t y, uint8_t z) {
	uint8_t outPacket[4];

	outPacket[0] = ACCEL_XYZ_PACKET;
	outPacket[1] = x;
	outPacket[2] = y;
	outPacket[3] = z;

	#ifdef DEBUG
	Serial.print(int8_t(x));
	Serial.print(" - ");
	Serial.print(int8_t(y));
	Serial.print(" - ");
	Serial.println(int8_t(z));
	#else
	tx = Tx16Request(XBEE_BASE_ADDR, outPacket, 4);

	xbee.send(tx);
	#endif
}

void send_prox(uint16_t val) {
	uint8_t outPacket[3];

	outPacket[0] = PROX_PACKET;
	outPacket[1] = uint8_t(val >> 8);
	outPacket[2] = uint8_t(val);

	#ifdef DEBUG
	Serial.print("\t\t\t");
	Serial.println(val);
	#else
	tx = Tx16Request(XBEE_BASE_ADDR, outPacket, 3);

	xbee.send(tx);
	#endif
}

void parse_data(uint8_t* data, uint8_t len) {
	switch(data[0]) {
		case MODE_PACKET: {
			if(len == 2) setMode(data[1]);
			break;
		}
		case CLEAR_PACKET: {
			reset();
			break;
		}
		case ACCEL_CONF_PACKET: {
			accel_enable(0);
			if(len >= 3) accel_reg_multi_write(data[1], &data[2], len-2);
			accel_enable(1);
			break;
		}
		case COLOR_PACKET: {
			if(len == 4) {
				rgb[0] = data[1];
				rgb[1] = data[2];
				rgb[2] = data[3];
			}
			break;
		}
		case COLOR_DUTY_PACKET: {
			if(len == 2) led_duty = data[1];
			break;
		}
		case COLOR_PERIOD_PACKET: {
			if(len == 2) led_period = data[1];
			break;
		}
		case COLOR_WAVEFORM_PACKET: {
			if(len == 2) led_waveform = data[1];
			break;
		}
		case VIBE_PACKET: {
			if(len == 2) vibe_level = data[1];
			break;
		}
		case VIBE_DUTY_PACKET: {
			if(len == 2) vibe_duty = data[1]; 
			break;
		}
		case VIBE_PERIOD_PACKET: {
			if(len == 2) vibe_period = data[1]; 
			break;
		}
		default: {
			//Hmm invalid packet
			break;
		}
	}
}

void setMode(uint8_t new_mode) {
	mode = new_mode;

	if(!(new_mode & (1 << PROX_MODE))) {
		for(uint8_t i = 0;i < PROX_AVG_LEN;i++) {
			prox_val[i] = 0;
		}
	}
}

/* ---- Blinking ---- */

void updateVibe(void) {
	if(vibe_on) vibe(vibe_level);
	else vibe(0);
}

void updateLEDs(void) {
	if(!led_waveform) {
		if(led_on) color(rgb[0], rgb[1], rgb[2]);
		else color(0, 0, 0);
	} else {
		float factor = 0;
		float duty = (float)led_duty/255.0;
		if(led_on) {
			factor = (float)(time_counter % led_period)/(duty*led_period);
		} else {
			int halfmod = (int)((time_counter % led_period)-duty*led_period);
			if(halfmod < 0) factor = 0;
			else factor = 1.0-(float)(halfmod)/((1.0-duty)*led_period);
		}
		factor = constrain(factor, 0, 1);
		Serial.println(factor);

		color(rgb[0]*factor, rgb[1]*factor, rgb[2]*factor);
	}
}

/* ---- Low Level ---- */

void color(uint8_t red, uint8_t green, uint8_t blue) {
	analogWrite(RED_LED_PIN, 255-red);
	analogWrite(GREEN_LED_PIN, 255-green);
	analogWrite(BLUE_LED_PIN, 255-blue);
}

void vibe(uint8_t level) {
	analogWrite(VIBE_PIN, level);
}

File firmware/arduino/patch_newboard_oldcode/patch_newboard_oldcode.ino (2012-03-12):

#include <XBee.h>

//Communication Type Constants
const int PROX_OUT_PACKET_TYPE = 1; //listening for this
const int PROX_IN_PACKET_TYPE = 2; //sending this
const int VIBE_OUT_PACKET_TYPE = 3;
//const int ACCEL_IN_PACKET_TYPE = 4;
const int CONFIG_OUT_PACKET_TYPE = 5; //listening for this
const int CONFIG_ACK_PACKET_TYPE = 6;
const int VIBE_IN_PACKET_TYPE = 7; // THIS IS NEW. For button presses.

//Communication variables
const int g_outPacketSize = 6;
const int g_inPacketSize = 5;
const int g_configPacketSize = 3;
const int g_configAckSize = 4;
static uint8_t inPacket[g_inPacketSize];
static uint8_t outPacket[g_outPacketSize];
static uint8_t configPacket[g_configPacketSize];
static int packet_cnt;

XBee xbee = XBee();
XBeeResponse response = XBeeResponse();
Rx16Response rx = Rx16Response();
Tx16Request tx;
uint16_t base_address = 0;
TxStatusResponse txStatus = TxStatusResponse();
const int RED_COLOR = 1;
const int BLUE_COLOR = 2;

//Communication -- addressing (need to be changed for each patch)
//PROX1_PLAYER1
int myColor = RED_COLOR;
static int myAddress = 1;
static int initialDelay = 0; //for staggering messages from sensors to avoid packet collision
static int ledFilter1 = 0x80; //128, 64, 32, and 16 -- for higher order bits
static int ledFilter2 = 0x08; //8, 4, 2, and 1 -- for lower order bits

// PROX2_PLAYER1
//int myColor = RED_COLOR;
//static int myAddress = 2;
//static int initialDelay = 10; //for staggering messages from sensors to avoid packet collision
//static int ledFilter1 = 0x40; //128, 64, 32, and 16 -- for higher order bits
//static int ledFilter2 = 0x04; //8, 4, 2, and 1 -- for lower order bits

// PROX3_PLAYER1
// int myColor = RED_COLOR;
// static int myAddress = 3;
// static int initialDelay = 20; //for staggering messages from sensors to avoid packet collision
// static int ledFilter1 = 0x20; //128, 64, 32, and 16 -- for higher order bits
// static int ledFilter2 = 0x02; //8, 4, 2, and 1 -- for lower order bits

// PROX4_PLAYER1
// int myColor = RED_COLOR;
// static int myAddress = 4;
// static int initialDelay = 30; //for staggering messages from sensors to avoid packet collision
// static int ledFilter1 = 0x10; //128, 64, 32, and 16 -- for higher order bits
// static int ledFilter2 = 0x01; //8, 4, 2, and 1 -- for lower order bits

// PROX1_PLAYER2
// int myColor = BLUE_COLOR;
// static int myAddress = 9;
// static int initialDelay = 0; //for staggering messages from sensors to avoid packet collision
// static int ledFilter1 = 0x80; //128, 64, 32, and 16 -- for higher order bits
// static int ledFilter2 = 0x08; //8, 4, 2, and 1 -- for lower order bits

// PROX2_PLAYER2
//int myColor = BLUE_COLOR;
//static int myAddress = 0x0A;
//static int initialDelay = 10; //for staggering messages from sensors to avoid packet collision
//static int ledFilter1 = 0x40; //128, 64, 32, and 16 -- for higher order bits
//static int ledFilter2 = 0x04; //8, 4, 2, and 1 -- for lower order bits

// PROX3_PLAYER2
// int myColor = BLUE_COLOR;
// static int myAddress = 0x0B;
// static int initialDelay = 20; //for staggering messages from sensors to avoid packet collision
// static int ledFilter1 = 0x20; //128, 64, 32, and 16 -- for higher order bits
// static int ledFilter2 = 0x02; //8, 4, 2, and 1 -- for lower order bits

// PROX4_PLAYER2
// int myColor = BLUE_COLOR;
// static int myAddress = 0x0C;
// static int initialDelay = 30; //for staggering messages from sensors to avoid packet collision
// static int ledFilter1 = 0x10; //128, 64, 32, and 16 -- for higher order bits
// static int ledFilter2 = 0x01; //8, 4, 2, and 1 -- for lower order bits


// Ordering
int seqNum;
int turnSeqNum;
int turnNum;

// Scheduling
const int DEFAULT_TURN_LENGTH = 1900;

long dataInterval = 50; // 20 Hz
long prevDataMillis = 0;
long xCheckInterval = 20; // 50 Hz
long prevCheckMillis = 0;
long blinkInterval = 100; // 10 Hz
long prevBlinkMillis = 0;
long turnLength; // will have to be set by config message
long prevTurnMillis = 0;
unsigned long currentMillis = 0;

// State variables
boolean running = false;
boolean blinking = false;
boolean waiting = false;

// Sensing
int proxPin = 4; //A4, 18 of 20
int proxBaseline = 250;
int proxReading = 0;
int touchThreshold = 1250;
boolean touched = false;
//might need to establish running average for capsense and look for spikes

//Feedback
int redLedPin = 8; //D11, 15 of 20
int blueLedPin = 10; //D10, 14 of 20
int greenLedPin = 9; //D9, 13 of 20
int vibePin = 6; //D6, 7 of 20
int onboardLEDPin = 7; // D8, red LED on seeduino film

//LED handling
int ledState;

//debug
boolean testing = false; // actually it's specifically testing sensors
boolean testingLights = false;

void setup() {
  initOutputs();
  // blink every color, buzz
  debugCycle();
  prevCheckMillis = prevTurnMillis = prevDataMillis = prevBlinkMillis = millis();

  turnLength = DEFAULT_TURN_LENGTH;
  xbee.begin(9600);
  Serial.print("patch_newboard_oldcode (addr = ");
  Serial.print(myAddress);
  Serial.println(")");
  packet_cnt = 0;
  seqNum = 0;
  turnSeqNum = 0;
  turnNum = 0;
  if (testing) {
    running = true;//testing
    blinking = true;//testing
    Serial.begin(9600);//testing*/
  }

}

void initOutputs() {
  pinMode(redLedPin, OUTPUT);
  pinMode(blueLedPin, OUTPUT);
  pinMode(greenLedPin, OUTPUT);
  pinMode(onboardLEDPin, OUTPUT);
  pinMode(vibePin, OUTPUT);
  color(0, 0, 0);
  analogWrite(vibePin, 0);
  ledState = LOW;
}

void debugCycle() {
  // Red + debug
  color(255,0,0);
  digitalWrite(onboardLEDPin, 1);
  delay(500);
  digitalWrite(onboardLEDPin, 0);
  delay(500);

  // Green + debug
  color(0,255,0);
  digitalWrite(onboardLEDPin, 1);
  delay(500);
  digitalWrite(onboardLEDPin, 0);
  delay(500);

  // Blue + debug
  color(0,0,255);
  digitalWrite(onboardLEDPin, 1);
  delay(500);
  digitalWrite(onboardLEDPin, 0);
  delay(500);
  color(0,0,0);

  // Vibe + debug
  analogWrite(vibePin, 255); 
  digitalWrite(onboardLEDPin, 1);
  delay(500);
  digitalWrite(onboardLEDPin, 0);
  delay(500);
  analogWrite(vibePin, 0); 
}
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

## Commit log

2012-01-13 Initial commit
    Code inherited from Amanda and Bruno
    [XBee-config-4-patches.ods]
2012-01-16 Starting on single patch - gradient vibration
    [Player.pde, Propinquity.pde, XBeeManager.pde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]
2012-01-18 work on gradient buzz
    Implementing gradient buzz, debugging via serial directly on seeeduino film
    [Propinquity.pde, XPan.pde, patch_single_patch_gradient_buzz.pde]
2012-02-02 Added Makefile to flash Arduino bootloader
    Allows you to flash the arduino bootloader onto the propinquity patch.
2012-02-02 Added latest eagle files for the patch
    [Patch-Prop1.brd, Patch-Prop1.sch]
2012-02-08 We have interfering packages with apiid 88
    [Propinquity.pde, XBeeManager.pde, XPan.pde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]
2012-02-21 extra pin map for the new board - not all original features yet, though
2012-02-21 the gloves can be made buzzing! with the new library
    [refactored_new_xbee_library.pde]
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2012-03-06 bugfix: don''t println prox values as that would go to the XBee
    [patch_sparkyjaneboard_talk_back.ino]
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2012-03-09 Can change colors and vibe now via keypresses that send packages. Read proximity code is still missing, though.
    [patch_newboard_oldcode.ino]
2012-03-27 Rename everything
    [XBee-config-4-patches.ods]
2012-03-28 Removed player.lst and xbees.lst, and added them to the ignore list, because there's no reason to version them. Moved more content from Propinquity.java to Graphics.java. Changed many ifs for switche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
2012-04-03 Replaced LevelSelect state int with an enum, and several if-else blocks with switches. Moved drawLevelSelect to LevelSelect.java where it should be.
2012-04-03 Created a new Logger class, and moved everything related to text or video logging into it. Removed the highscore game state and its associated methods, which currently did nothing. More delicious com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
2012-04-05 Serious cleanup in XBeeManager
    Simpilified the code
    Now holds XBeeReaders open instead of open closing all the time
    Uses wait/notify
    Other tweaks
    Replaced PApplet.println with System.out.println everywhere
2012-04-30 fixing garbage left from previous merge
    [patch.ino]
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2012-05-02 Refactoring and building up new hardware structure
    Adding new classes to represent packets, patches and gloves
    Preparing to split GUI out of the XbeeManager/XbeeBaseStation
    Preparing to switch Xbee APIs
2012-05-02 duty cycle/period on vibe and LEDs working, but dynamically changing values not so much
2012-05-02 fixed dynamic setting of period/duty
    [patch.ino]
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2012-05-07 Spring cleaning and reorganization of Level.java, mainly grouping methods logically, removing dead code, and setting proper access modifiers.
2012-05-07 Updates to missing part of the protocol + bugs
    Updated the period mechanism so that the duty field represents a
    fraction of the the period. e.g. duty = 100 is 100/255 of the period.
    This a more "natural" behavipr
    Updated the active flag to work more consistently. Current disbale
    everything when 0, but nothing is reset. This reset functionalilty can
    easily be commented back in.
    Added the missing protocol elements for the vibe
    [patch.ino]
2012-05-07 Modified PacketType to reflect patch.ino
    Now matches the packet type numbers in the arduino code (patch.ino)
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2012-05-09 Fixed the way score propagated, removed dead code, and started trying to get collision filtering to work for transferred particles.
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2012-05-16 Rebuilt vincent's idea for frame resending with idep threading
    There is now one thread for each frameID, that way the first "timeout",
    is always 100ms after the first packet was sent, before it was sending a
    burst of all the packets every 100ms
2012-05-17 Gravity has been cut down to a single method, now scales to any number of players.
2012-05-18 Somewhat hack build but functional
    Update TODO to reflect findings
    Serious issues with minimal packet sending as there is order loss or
    packet loss resulting in essentially arbitray behavior. Currently I have
    removed all the mechanism that prevent resending when the "new" value is
    equal to the "old" value. Thus if you set the level to 255 when it is
    already 255 it will resend nevertheless. This leads to huge amounts of
    "excess" traffic however the result is quite usable since it curshes any
    asyn/packet loss issues.
    I have some ideas for solving this noted in todo, as well as some weird
    bugs to resolve.
    The Prox/Red LED issue is very serious on the patch and needs to be
    isolated. As of now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
2012-05-18 Added a daemon mechanism for path and glove + playtest updates
    Trying a regular daemon mechanism. So far, not good, more after the
    playtest
    Also added better printout for mystery xbees
    Small bug fixes
2012-05-23 Various fixes
    Tweaks to patch and glove firmware.
    Just a little cleanup, keeping the protocol standard
    Fixed a little typo
    Removed negative code from player
    Javadoc warning fix
    [glove.ino, patch.ino]
2012-05-24 Making the build build
    Currently working on BooperLevel and HealthLevel. Neither are
    functioning yet
2012-05-24 More tweaks to the new mechanics
    Added a color change for coop on the patches. Fixed some bug
    [patch.ino]
2012-05-28 Tweaks for gameplay and metaballs
    -Added more hacky adjustements to metaballs
    -Trying to note the hacks with todos
    -Added two versions of the partlice sprite.
    -Added a bump features which puts random energy in the particles on pause
    -Added functionality to fuse balls of any color.
    -Tweaked thres shader
2012-06-13 Removed old docs
    [XBee-config-4-patches.ods]
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2012-10-03 Added step-up schematics
    [IND_DCDC.brd, IND_DCDC.sch]
2013-01-17 Added a schematic for v2 of Patch -Listed some question and thoughs in the sch -Still missing the LED driver
    [Patch-Prop.sch]
2013-01-17 Added LED driver in MSOP8 package + raw brd file
    [Patch-Prop.brd, Patch-Prop.sch]
2013-01-17 Tweaking naming and notes
    [Patch-Prop.brd, Patch-Prop.sch]
2013-01-18 Working on PCB
    [Patch-Prop.brd, Patch-Prop.sch]
2013-01-19 Tentative part layout for propinquity board
    [Patch-Prop.brd, Patch-Prop.sch]
2013-01-19 All routed except for LEDs (which will be hard)
    [Patch-Prop.brd, Patch-Prop.sch]
2013-01-19 Tweaks, still 4 drc errors
    [Patch-Prop.brd]
2013-01-19 More small fixes
    [Patch-Prop.brd]
2013-01-20 About to move uC
    [Patch-Prop.brd]
2013-01-20 Moved uC now routing LEDs
    [Patch-Prop.brd, Patch-Prop.sch]
2013-01-20 Working on LED routing, remove Xbee reset
    [Patch-Prop.brd, Patch-Prop.sch]
2013-01-20 Tweaking route style and doing cleanup
    [Patch-Prop.brd, Patch-Prop.sch]
2013-01-21 Expanded board to fit mounting holes. Used extra space for breakout pins
    [Patch-Prop.brd, Patch-Prop.sch]
2013-01-21 Smashed and adjusted part names, added pin annotation
    [Patch-Prop.brd, Patch-Prop.sch]
2013-01-21 Added project name to tname/bname
    [Patch-Prop.brd]
2013-01-21 Some small fixes, bigger font. First pass gerber file
    [DRILEGEND.CFG, Patch-Prop.brd, Patch-Prop.sch]
2013-01-22 Clean up
    [DRILEGEND.CFG]
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2013-01-29 Smaller cream layers
    [Patch-Prop.brd]
2013-02-01 Changed fuses and makefile
    -Brown out level was improperly defined in fuses
    -Made the makefile use env variable for programer
2013-02-01 Added some basic accelerometer code
    -Added register definitions
    -Added basic code to read three axis values
2013-02-04 Updated patch firmware, complete but untested:
    -Basic support for acceleromter XYZ output
    -Simple remote CONF for accel
    -Some resiliency/error checking in case accel doesn't work
    -General cleanup, better code practices
    -New mode variable allowing to selectively enable/disable periferals
    [patch.ino]
2013-02-04 Updated software to reflect new protocol and accel
    -Changed protocol command values in java
    -Added basic support for the acceleromters in the patch/xbee classes
    -Added support for accelerometers in the debugger
    Untested
2013-02-04 Some small but fixes after real world testing
    [patch.ino]
2013-02-08 Incremental improvements to the patch code
    -Less aggresive low pass
    -Cutoff below a certain LED value
2013-02-08 Changed default file state
    [Patch-Prop.brd]
2013-02-08 Added a throttled send mechanism.
    -Corrected a bug in MIN_PACK which sent large amounts of clear messages
    -Added a throttled mode preventing more than 1 packet per second
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2013-02-08 Added support for interrupts, activation modes, acceleration simulation, started on AccelLevel which is the Orb game
2013-02-09 Added glitch-resistance, fine-tuning
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2013-04-21 Created a v2.1 of the board with first changes
    -Replaced the LDO for a more standard footprint with an inverted en pin
    -Added ignores for tmp eagle files
    [Patch-Prop.brd, Patch-Prop.sch]
2013-04-21 Switch for charging topology, added jumper for FTDI, Stepup to V+
    -Added a header for a switch between battery and V+. When the switch is
    off, only the charger IC is still connected to the battery
    -Disconnected FTDI from +3v3 now jumper to V+
    -Now connected setupup to V+ instead of +3v3
    [Patch-Prop.brd, Patch-Prop.sch]
2013-04-21 Flipped transistor footprint
    Flipped to the more common BCE/DGS layout
    [Patch-Prop.brd, Patch-Prop.sch]
2013-04-21 Working on routing, noting progress
    [Patch-Prop.brd]
2013-04-21 Routing away
    [Patch-Prop.brd]
2013-04-21 Finished routing changes
    [Patch-Prop.brd]
2013-04-21 Upped the DRC tolerance to 10mil where possible
    [Patch-Prop.brd]
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

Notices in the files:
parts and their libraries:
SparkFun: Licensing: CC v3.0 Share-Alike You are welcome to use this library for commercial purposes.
